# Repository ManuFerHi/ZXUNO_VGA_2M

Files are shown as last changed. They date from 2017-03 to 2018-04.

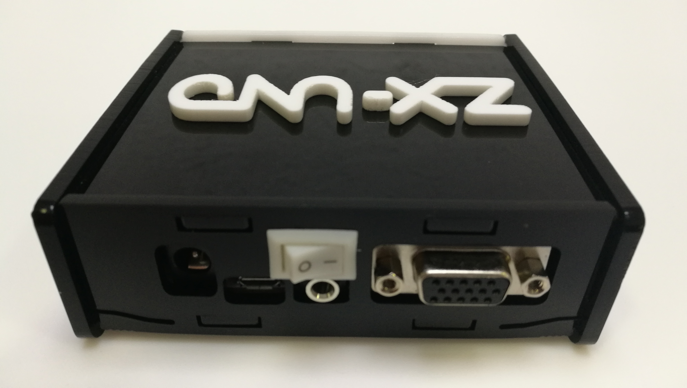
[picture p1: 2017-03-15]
Pics/IMG_20170307_124106.jpg

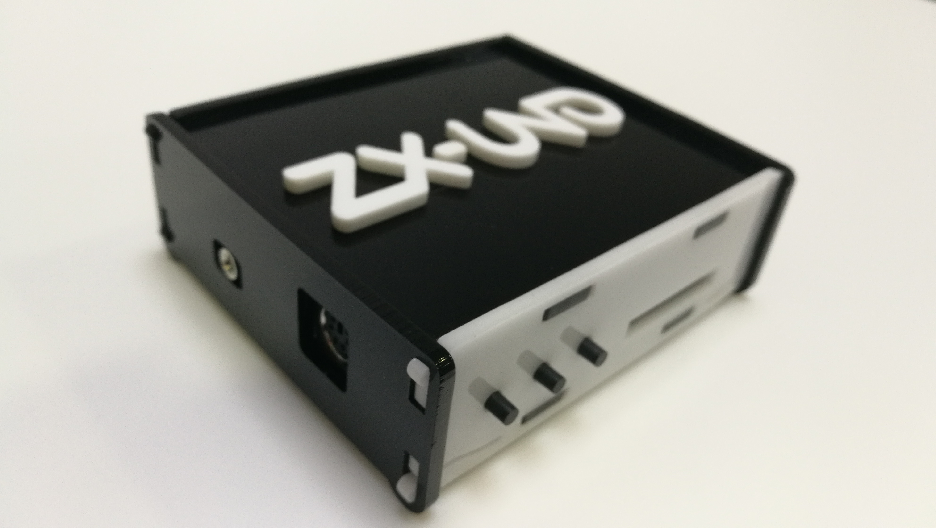
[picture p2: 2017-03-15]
Pics/IMG_20170307_124134.jpg

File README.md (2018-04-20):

# ZXUNO_VGA_2M
FPGA BOARD based on ZX-UNO project, this version include 2Mb SRAM, W25Q128 Flash chip and 2 joystick ports. VGA and RGB native output.




For more information, contact with manuferhi@gmail.com

Based on ZX-UNO project by Superfo, Mcleod, Quest, AVillena and Hark0.
http://zxuno.speccy.org/

(CC BY-SA)License.

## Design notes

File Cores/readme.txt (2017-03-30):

Para instalar un core o reemplazar versión, descargar el fichero CORE(X).ZX1 y renombrar X=SLOT que ocupa en vuestro Zx-Uno, colocar en el directorio raiz y seleccionar en bios menú update el slot dónde alojar el core.

To install a core or replace version, download the file CORE (X) .ZX1 and rename X = SLOT that occupies in your Zx-Uno, place in the root directory and select in bios menu update the slot where to host the core.

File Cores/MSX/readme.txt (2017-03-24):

Autor Fabio.

25/03/2017

Add VGA video output.

I made a MSX1 core, with a SCC Megaram from OCM. Specifications:

- MSX1 USA, 60Hz vertical frequency.
- 128K RAM Mapper.
- 128K Nextor (MSX-DOS2 evolution) ROM with SD driver.
- 256K of RAM to Megaram SCC/SCC+ from OCM project.
- Keyboard PT-BR layout (for a while).
- Simple switched I/O ports (no software yet).
- Multiple boards, incluing ZX-Uno.
- CVBS video only, no scandoubler yet.

The binaries are located here:

https://drive.google.com/drive/folders/0B5wpc_jDN_n0Z1BvSms2YWJHWGc

Format a SD Card in FAT16 (4GB max) and unzip the 'msx1_sd_files.zip' file in SD card root.

The MSX 1 FPGA contains a IPL loader to clear the RAM and load the 'NEXTOR.ROM' SD file to RAM. The ROM is implemented in Xilinx BlockRAM.

CTRL+ALT+DEL is soft reset, CTRL+ALT+F12 is hard reset (run IPL again) and CTRL+ALT+BACKSPACE is ZX-Uno Standard, reload first core from SPI Flash.

The joystick port is mapped to JoyMega, configure the ZX-Uno hardware to SEGA Genesis joypad.

To load ROM in SCC Megaram, uses the ROMLOAD.COM (it is in SD files) with '/S' switch for starting:

ROMLOAD game.rom /S

The core is in beta stage yet, sources will be released soon.

Thanks.

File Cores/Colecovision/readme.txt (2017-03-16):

# colecofpga
Colecovision FGPA port from old PACE project.

The original project information is here:
http://members.iinet.net.au/~msmcdoug/pace/Nanoboard/nanoboard.html

This project is a ColecoFPGA design port to the Terasic DE-1 and DE-2 development boards, ZX-Uno board and a stand-alone version with a EP2C5 Chinese board.

The Hardware folder is the Eagle project for the prototype. In Synth folder there are projects for all cards. The prototype 1 did not work and is abandoned, the project with the EP4C10 card is not completed.

The second prototype use SNES control to emulate all of the original joystick buttons. Holding TL button the original buttons simulate:

<pre>
Y      => 1
X      => 2
B      => 3
A      => 4
SELECT => 5
START  => 6
</pre>

Holding TR button the original buttons simulate:

<pre>
Y      => 7
X      => 8
B      => 9
A      => 0
SELECT => *
START  => #
</pre>

Holding START and SELECT together resets the machine, returning in the multcart menu.

The B button and Y (auto-fire) is the fire 1 of original joystick. The A button and X (auto-fire) is the fire 2.

For the DE-1, DE-2 and ZX-Uno boards the PS/2 keyboard emulates the original joystick:

The arrow keys simulate the original directional. Z key is the 'fire 1', X key is 'fire 2', 0-9 is '0-9', Q key is '*' and W key is '#'. ESC key resets the machine. For the ZX-Uno the joystick port also works for directionals and fire 1.

The key combination CTRL+ALT+BACKSPACE, on ZX-Uno version, reloads the main core of Xilinx, returning to the main menu.

In this circuit the BIOS ROM is loaded from the SD card as well as the ROM multcart. In the source folder 'SD_Card' contains all necessary files to the SD card. Format it to FAT16 and copy the files.

In multcart menu, use the directionals to navigate the ROMs and use FIRE 1 button to load the selected ROM.

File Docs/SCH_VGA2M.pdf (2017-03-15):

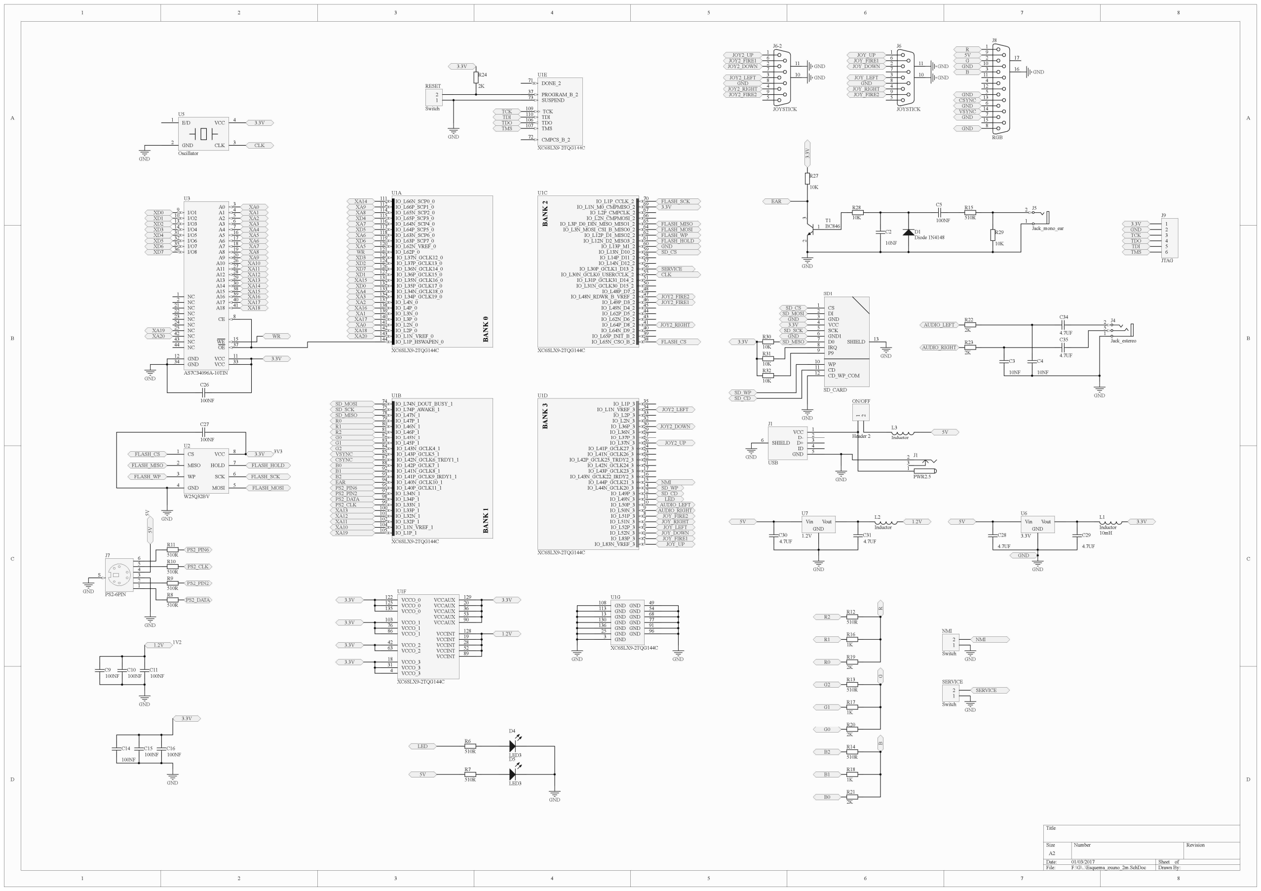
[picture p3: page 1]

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
Title

Size | Number | Revision
A2
Date: | 01/03/2017 | Sheet of
File: | F:\G\..\Esquema_zxuno_2m.SchDoc | Drawn By:
144 | IO_L1P_HSWAPEN_0 | BANK ⁰ IO_L1N_VREF_0 143 | IO_L2P_0 142 | IO_L2N_0 141 | IO_L3P_0 140 | IO_L3N_0 139 | IO_L4P_0 138 | IO_L4N_0 137 | IO_L34P_GCLK19_0 134 | IO_L34N_GCLK18_0 133 | IO_L35P_GCLK17_0 132 | IO_L35N_GCLK16_0 131 | IO_L36P_GCLK15_0 127 | IO_L36N_GCLK14_0 126 | IO_L37P_GCLK13_0 124 | IO_L37N_GCLK12_0 123 | IO_L62P_0 121 | IO_L62N_VREF_0 120 | IO_L63P_SCP7_0 119 | IO_L63N_SCP6_0 118 | IO_L64P_SCP5_0 117 | IO_L64N_SCP4_0 116 | IO_L65P_SCP3_0 115 | IO_L65N_SCP2_0 114 | IO_L66P_SCP1_0 112 | IO_L66N_SCP0_0 111

U1A

XC6SLX9-2TQG144C

105 | IO_L1P_1 | BANK ¹ IO_L1N_VREF_1 104 | IO_L32P_1 102 | IO_L32N_1 101 | IO_L33P_1 100 | IO_L33N_1 99 | IO_L34P_1 98 | IO_L34N_1 97 | IO_L40P_GCLK11_1 95 | IO_L40N_GCLK10_1 94 | IO_L41P_GCLK9_IRDY1_1 93 | IO_L41N_GCLK8_1 92 | IO_L42P_GCLK7_1 88 | IO_L42N_GCLK6_TRDY1_1 87 | IO_L43P_GCLK5_1 85 | IO_L43N_GCLK4_1 84 | IO_L45P_1 83 | IO_L45N_1 82 | IO_L46P_1 81 | IO_L46N_1 80 | IO_L47P_1 79 | IO_L47N_1 78 | IO_L74P_AWAKE_1 75 | IO_L74N_DOUT_BUSY_1 74

U1B

XC6SLX9-2TQG144C | BANK ² | IO_L1P_CCLK_2 | 70
| | IO_L1N_M0_CMPMISO_2 | 69
| | IO_L2P_CMPCLK_2 | 67
| | IO_L2N_CMPMOSI_2 | 66
| | IO_L3P_D0_DIN_MISO_MISO1_2 | 65
| | IO_L3N_MOSI_CSI_B_MISO0_2 | 64
| | IO_L12P_D1_MISO2_2 | 62
| | IO_L12N_D2_MISO3_2 | 61
| | IO_L13P_M1_2 | 60
| | IO_L13N_D10_2 | 59
| | IO_L14P_D11_2 | 58
| | IO_L14N_D12_2 | 57
| | IO_L30P_GCLK1_D13_2 | 56
| | IO_L30N_GCLK0_USERCCLK_2 | 55
| | IO_L31P_GCLK31_D14_2 | 51
| | IO_L31N_GCLK30_D15_2 | 50
| | IO_L48P_D7_2 | 48
| | IO_L48N_RDWR_B_VREF_2 | 47
| | IO_L49P_D3_2 | 46
| | IO_L49N_D4_2 | 45
| | IO_L62P_D5_2 | 44
| | IO_L62N_D6_2 | 43
| | IO_L64P_D8_2 | 41
| | IO_L64N_D9_2 | 40
| | IO_L65P_INIT_B_2 | 39
| | IO_L65N_CSO_B_2 | 38

U1C

XC6SLX9-2TQG144C BANK ³ | IO_L1P_3 | 35
IO_L1N_VREF_3 | 34
IO_L2P_3 | 33
IO_L2N_3 | 32
IO_L36P_3 | 30
IO_L36N_3 | 29
IO_L37P_3 | 27
IO_L37N_3 | 26
IO_L41P_GCLK27_3 | 24
IO_L41N_GCLK26_3 | 23
IO_L42P_GCLK25_TRDY2_3 | 22
IO_L42N_GCLK24_3 | 21
IO_L43P_GCLK23_3 | 17
IO_L43N_GCLK22_IRDY2_3 | 16
IO_L44P_GCLK21_3 | 15
IO_L44N_GCLK20_3 | 14
IO_L49P_3 | 12
IO_L49N_3 | 11
IO_L50P_3 | 10
IO_L50N_3 | 9
IO_L51P_3 | 8
IO_L51N_3 | 7
IO_L52P_3 | 6
IO_L52N_3 | 5
IO_L83P_3 | 2
IO_L83N_VREF_3 | 1

U1D

XC6SLX9-2TQG144C

PROGRAM_B_2 37

CMPCS_B_2 72

DONE_2 71

TCK 109
TDI 110
TMS 107 TDO 106

SUSPEND 73

U1E

XC6SLX9-2TQG144C

VCCAUX | 129
VCCAUX | 20
VCCAUX | 36
VCCAUX | 53
VCCAUX | 90
VCCINT | 128
VCCINT | 19
VCCINT | 28
VCCINT | 52
VCCINT | 89

VCCO_0 122
VCCO_0 125
VCCO_0 135

VCCO_1 103
VCCO_1 76
VCCO_1 86

VCCO_2 42
VCCO_2 63

VCCO_3 18
VCCO_3 31
VCCO_3 4

U1F

XC6SLX9-2TQG144C

GND 108
GND 113
GND 13
GND 130
GND 136
GND 25
GND 3
GND | 49
GND | 54
GND | 68
GND | 77
GND | 91
GND | 96

U1G

XC6SLX9-2TQG144C

A15 | 38 A14 | 30 A13 | 29 A12 | 28 A11 | 27 A10 | 26 A9 | 20 A8 | 19
WE | 15
A17 | 40
A7 | 18 A6 | 17 A5 | 16 A4 | 7
A3 | 6
A2 | 5
A1 | 4
A0 | 3
VCC | 33 GND 12
OE | 37

NC 21

I/O1 9

NC 22

I/O2 10

NC 23

I/O3 13

NC 24

I/O4 14

NC 25

I/O5 31

NC 42

I/O6 32

NC 43

I/O7 35

NC 44

GND 34

A16 | 39
VCC | 11
A18 | 41 NC 2

NC 1

CE 8

I/O8 36

U3

AS7C34096A-10TIN

E/D 1

GND 2

VCC | 4
CLK | 3

U5

Oscillator

Vin Vout
GND

U6

3.3V

Vin Vout
GND

U7

1.2V

2

1

5

J4

Jack_estereo

2

1

J5

Jack_mono_ear

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
JOYSTICK

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
PS2-6PIN

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
JTAG 1

2

ON/OFF

Header 2

1

2

RESET

Switch

D1
Diode 1N4148

D4

LED3
D5

LED3

3
1 2

T1
BC846

10mH

L1

Inductor

L2

Inductor

L3

Inductor

510R

R6

510R

R7

510R

R8

510R

R9

510R

R10

510R

R11

510R

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
10NF

C2

10NF

C3

10NF

C4

100NF

C11

100NF

C14

100NF

C26

100NF

C27

100NF

C5

100NF

C9
100NF

C10

4.7UF

C28

4.7UF

C29
4.7UF

C30
4.7UF

C31

4.7UF

C34

4.7UF

C35

FLASH_SCK

FLASH_SCK

3.3V

FLASH_MISO
FLASH_MOSI
FLASH_WP
FLASH_HOLD
GND
SD_CS

CLK

FLASH_CS

SD_MOSI
SD_SCK
SD_MISO
R0
R1
R2
G0
G1
G2
VSYNC
CSYNC
B0
B1
B2
EAR
PS2_PIN6
PS2_PIN2
PS2_DATA
PS2_CLK
XA13
XA12
XA11
XA10
XA19

XA14
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
XA15
XD0
XA4
XA3
XA2
XA16
XA1
XA17
XA0
XA18
WR | XA20

3.3V

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
XA10
XA11
XA12
XA13
XA14
XA15
XA16
XA17
XA18

XA19
XA20

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
3.3V

GND

3.3V

GND

CLK

3.3V

3.3V

GND

3.3V

3.3V

FLASH_CS

FLASH_MISO

FLASH_WP

FLASH_HOLD

FLASH_MOSI

3.3V

GND

PS2_PIN6

PS2_CLK

PS2_PIN2

PS2_DATA ⁵V

GND

1.2V

GND

100NF

C15
100NF

C16

3.3V

GND

3.3V

LED
AUDIO_LEFT
AUDIO_RIGHT
JOY_FIRE2
JOY_RIGHT
JOY_LEFT
JOY_DOWN
JOY_FIRE1
JOY_UP

1.2V

GND | GND

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
5V | 1.2V

GND

5V | 3.3V

3.3V
GND
TCK
TDO
TDI
TMS

JOY_UP

JOY_DOWN

JOY_LEFT

JOY_RIGHT

JOY_FIRE1

GND

JOY_FIRE2

SD_CS
SD_MOSI
GND
3.3V
SD_SCK
GND
3.3V | SD_MISO

GND

GND

5V

AUDIO_LEFT

AUDIO_RIGHT

GND ³.3V

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
VSYNC

CSYNC

5V

CS 1

MISO 2

WP 3

GND 4

VCC | 8
HOLD | 7
SCK | 6
MOSI | 5

U2

W25Q32BV

VCC | 1
D- | 2
D+ | 3
ID | 4
GND | 5

SHIELD 6

J1

USB

CS 1
DI 2
GND 3
VCC 4
SCK 5
GND1 6
D0 7
IRQ 8
P9 9

WP 10
CD 11
CD_WP_COM 12

SHIELD 13

SD1

SD_CARD

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
J6-2

JOYSTICK

1

2
3

J1

PWR2.5

510R

R12

510R

R13

510R

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
R G B

3V3 5V

1V2

GND

JOY2_UP
JOY2_FIRE1
JOY2_DOWN

JOY2_LEFT
GND
JOY2_RIGHT
JOY2_FIRE2

JOY2_UP

JOY2_FIRE1

JOY2_DOWN

JOY2_LEFT

JOY2_RIGHT

JOY2_FIRE2

1

2

NMI

Switch

1

2

SERVICE

Switch

NMI

NMI

GND

GND

SERVICE

SERVICE

SD_WP
SD_CD

SD_WP
SD_CD

GND

GND

GND

GND

GND

GND

GND

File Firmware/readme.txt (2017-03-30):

Rename file to firmware.zx1 and put in SD root. Select in bios menu update option "Update bios" then select SD option.

Renombrar el fichero a firmware.zx1 y colocarlo en el directorio raiz de la SD, seleccionar en la bios menú update opción update bios y opción SD.

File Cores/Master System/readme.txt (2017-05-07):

This is a port of the Ben Leperchey's Sega Master System HDL core to the ZX-UNO board.
Original source code: https://github.com/ben0109/Papilio-Master-System

All credits go to Ben. 
Ben's Blog: http://fpga-hacks.blogspot.com.es/

Ported to ZX-UNO by Quest of ZX-UNO team (http://www.zxuno.com)
2 joy supported.

As per original author's request, and following the ZX-UNO open source rules, every source code change, addition, improvement, etc, is available freely at ZX-UNO SVN repository

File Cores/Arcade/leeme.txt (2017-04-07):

Características comunes a todos los cores:
------------------------------------------

- 2 modos de vídeo seleccionables: RGB (PAL60Hz) y VGA 60Hz (conmutable con tecla Bloq. Despl / Scroll Lock)

- Soporte de scanlines en VGA (conmutable con la tecla "-" del teclado numérico)

- Autodetección del modo de vídeo de la BIOS del ZX-UNO.

- Reset de la máquina (pulsando F12)

- Añadido Master Reset para volver al core de Spectrum (con Ctrl+Alt+Backspace)

- Controles de jugador tanto en teclado como en joystick:

 ** Las direcciones en el teclado son, tanto los cursores como QAOP. Disparos 1 y 2 en teclas Z y X. También comparten dichas teclas en algunos casos la inserción de moneda y el boton Start. Lo mismo para el joystick. Es necesario un joystick o pad de 2 botones. Dependiendo de cada juego el mapeo de estas funciones puede estar intercambiado (para evitar meter monedas cuando disparas, etc, ya que cada juego lo hace diferente).

- Implementada conmutación opcional para el giro de 90º en las direcciones de los controles (pulsando la tecla TAB). Por defecto arrancan con los controles normales, para el uso de pantallas verticales. Si tienes la pantalla en horizontal (lo más habitual), la imagen se ve girada, pero para ayudar en el control, y que sea más natural y acorde con lo que se ve, pulsando TAB se consigue que las direcciones arriba-abajo estén intercambiadas con izquierda-derecha. Afecta por igual al joystick y al teclado.

COMO GRABAR LOS CORES EN EL ZX-UNO:
-----------------------------------
Para grabar los cores en el ZX-UNO, renombrar cada archivo .ZX1 a COREx.ZX1, siendo "x" el numero de slot que queremos que ocupe en la memoria flash del ZX-UNO. Copiar a la tarjeta SD, encender el ZX-UNO, pulsar F2 al arranque para entrar en BIOS, ir a la pestaña Upgrade y seleccionar el slot correspondiente, elegir grabar desde SD y al finalizar escribir el nombre del core.

Para lanzar el core una vez grabado, al arranque del Zx-UNO, pulsar Bloq. Mays (Caps Lock) y elegirlo de la lista que sale.

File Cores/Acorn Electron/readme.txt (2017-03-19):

TEST1 (8-Ene-2016)

Es un port del trabajo original de David Banks (hoglet), como todo lo que tenemos de Acorn hasta el momento (fuentes originales en https://github.com/hoglet67/ElectronFpga).

Ya está subido el fuente para el ZX-UNO y el .bit tanto para v2 como v3 (vale para ambos puesto que no usa la SRAM) en el repositorio SVN habitual.

Funciones actuales:

- Salida vídeo compuesto/RGB y VGA 50Hz seleccionables vía teclado. Por defecto arranca en RGB/Vcomp. Tecla RePag = VGA, tecla AvPag = RGB/Vcomp. También hay otros modos (60Hz, etc) usando combinaciones de ctrl+CapsLock+1 al 4)
- Soporte SD/MMC, vía archivos de imagen ".MMB" (BEEB.MMB, que son contenedores de imágenes de disquete). Explicado más abajo para que funcione correctamente (al igual que pasa con el core de BBC Micro)
- Carga de software via cinta/audo por el puerto EAR del ZX-UNO.
- Teclado PS/2 (mapeado a teclado inglés)
- Sonido estándar.
- Reset (tecla F10 y ctrl+F10)

El core usa una rom (Smart SPI) que lee de la SD un archivo normalmente grande, que contiene imágenes de disquete, que debe tener el nombre de BEEB.MMB en el directorio raíz. Este archivo lo podéis crear vosotros mismos con una utilidad incluida (MMBImager.exe) o bien descargar uno preparado con software y juegos, de los que hay por la red para Acorn Electron (por ejemplo, este, ajeno a este foro: https://mega.nz/#!ZE8FxQSC!EN89saPfSfO0 ... SAOvhdbGJA)

Pero no basta con copiarlo directamente a la SD si ya hay cosas dentro, y seguramente al 99% que no lea correctamente dando corrupciones. Por tanto para que funcione 100% bien:

1- Formatear una SD (si no es muy grande, mejor) en FAT o FAT32, pero NO en formato rápido (en Windows, desmarcar la casilla de formato rápido). Esto es muy importante.
2- Copiar a la SD el archivo BEEB.MMB, de modo que este sea el PRIMER archivo que se copia a la SD.
3- Si se desea, ya se pueden copiar otros archivos a la SD para usar con otros cores, pero SIEMPRE debe mantenerse el BEEB.MMB como el primero que se copió a la SD. Es muy importante.

Una vez metida la SD en el ZX-UNO y arrancado el core, si el archivo de antes (BEEB.MMB) está bien grabado y reconoce bien la SD. Al arrancar debería aparecer:

CÓDIGO: SELECCIONAR TODO
Acorn Electron
Smart SPI
BASIC
>

Automáticamente se automonta el disco 0 de la imagen, podemos ver su contenido tecleando *CAT
Por algún motivo que desconozco, a diferencia de lo que pasa en el core de BBC micro que autoarranca si el disco tiene Boot al pulsar shift+F10 y tampoco van los comandos de carga de binarios (como *RUN) pero sí podemos cargar cargadores BASIC sin problemas:

Para cargar el menú de juegos que viene en la imagen precargada que comentaba antes, tecleamos: CHAIN"MENU"

Para cargar desde cassete/Entrada de audio EAR, he incluido en la carpeta "varios" el programa FreeUEF.exe que sirve para reproducir cintas en formato UEF en el PC. Viene una de ejemplo de una revista. También las convierte a WAV para reproducirlos luego desde otro dispositivo como el móvil.

Para cargar de cinta: Tecleamos primero: *TAPE
Y después: CHAIN"" y pulsamos PLAY.

Y eso es todo. Para resetear, en este caso es F10 o ctrl+F10.

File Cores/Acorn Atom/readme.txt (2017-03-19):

TEST1 (17-Ago-2015)

El código original del usuario Hoglet, en el que se ha basado el port, está disponible aquí: https://github.com/hoglet67/AtomFpga.

Post escrito por Quest originalmente en Zona de Pruebas.
Enlace original:
http://www.zonadepruebas.com/viewtopic. ... 754#p59754

Otro sistema más funcional en el ZX-UNO (Y van 5) :D

En esta ocasión he portado el core del Acorn Atom
Más abajo pongo el link de descarga del bitfile / mcs para el que lo quiera probar :)

Tiene soporte para cargar el software con tarjeta SD.

Como en la ocasión anterior con el de SMS, ha habido que remapear todos los pines, crear nuevos relojes a aprtir de nuestro oscilador de 50Mhz, eliminar señales que daban problemas (como las de los joystick), cambiar ligeramente el código del teclado para que funcionara en el ZX-UNO, etc. El código original, en el que se ha basado el port está disponible aquí: https://github.com/hoglet67/AtomFpga , del usuario Hoglet.

Para hacerlo funcionar en el ZX-UNO:

- Meter el bitfile a la FPGA (o el mcs para la flash)
- Enchufar un teclado PS/2 al l ZX-UNO
- Enchufar la plaquita VGA al conector J8 y conectarlo a un monitor VGA normal. (no va por vídeo compuesto, sólo VGA de momento)
- Enchufar el jack de salida de audio a unos altavoces.
- Preparar una tarjeta SD formateada en FAT. Bajad de aquí: http://www.stardot.org.uk/forums/viewto ... =44&t=6544 el archivo "AtomSoftwareArchive_20150504_V8.zip" y descomprimidlo tal cual en la raíz de la SD (si no va la SD, probad con otra distinta). Y meterla en el ZX-UNO.

Y ahora, a funcionar:

- Al enchufar el ZX-UNO ya arranca en modo BASIC del Atom. El bitfile del core ya viene con la extensión AtoMMC2 incorporada, con lo cual, disponemos de carga mediante la SD:
- Para lanzar el menú de selección de software que hemos cargado en la SD previamente, pulsamos SHIFT+F10 (si no va a la primera intentarlo más veces, a veces no va 100% fino)
- A disfrutar.

- Para volver a sacar el menú: SHIFT+10
- Resetear el Atom: F10
- Modos turbo: F1 = 1Mhz, F2 = 2Mhz, F3 = 4Mhz, F4 = 8Mhz
- El mapeado del teclado es inglés. Tenedlo en cuenta, porque no coinciden algunas teclas con el español. Mirad una foto de uno inglés para comparar.

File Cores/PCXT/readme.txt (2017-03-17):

Autor Distwave.

- Eliminado el PSG para el sonido Tandy 3-voice. Se ha reducido notablemente el ruido de fondo.
- Solucionados los gitches en modo texto.
- BIOS Incorporada en el core, ya no es necesario grabarla en los últimos 8 KB de la SD. Ahora se aloja en la BRAM utilizada como memoria de vídeo y el bootloader la copia a la memoria RAM en el primer arranque (tal y como sugirió antoniovillena).
- Frecuencia de trabajo de la memoria SRAM aumentada de 50 MHz a 75 MHz. Este cambio aumenta el rendimiento del core notablemente, aunque el procesador siga funcionando a 25 MHz.
- Mapeo directo de los 2 MB de SRAM en los primeros 2 MB direccionables. La distribución de la memoria queda de la siguiente forma:
· 640 KB de memoria convencional
· 224 KB de memoria superior
· 32 KB para alojar la BIOS
· 64 KB de memoria alta
· 448 KB de memoria extendida (XMS)

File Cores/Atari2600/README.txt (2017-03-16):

Port of the A2601 FPGA implementation for the ZXUNO
---------------------------------------------------------------------------------

Limitations:
- Needs a PS/2 keyboard to access the menu (Esc key) and load roms
- supports only player one controller

All zxuno related files including the Quartus project files are in the 'zxuno' subdirectory.

2016 DistWave

Original readmes:

Port of the A2601 FPGA implementation for the MiST
---------------------------------------------------------------------------------

Buttons:
- right MiST button -> Start
- Keyboard 1        -> Select
- Keyboard 2        -> BW/Color (yellow led on = Color)
- Keyboard F12      -> OSD to select roms from the sd card (needs extension .a26)

Current limitations:
- supports only the common Atari bank switching schemes
- no illegal opcodes

All MiST related files including the Quartus project files are in the 'mist' subdirectory.

Homepage: http://ws0.org/tag/ma2601/

Original readme below :)

Port of the A2601 FPGA implementation for the Turbo Chameleon
---------------------------------------------------------------------------------

The ROM cartridge is the GPL licensed game Hunchy, see
http://www.atariage.com/forums/topic/67953-hunchy-my-first-2600-homebrew-game/
converted to hex file format with 
http://www.ht-lab.com/freeutils/bin2hex/bin2hex.html

Copyright 2012 Frank Buss

Original readme:

A2601: An FPGA-based clone of the Atari 2600 video game console (Release 0.1.0)
---------------------------------------------------------------------------------

This archive contains source code for VHDL implementation and Python script 
utilities for the A2601 video game console project.

VHDL source code provided includes implementation of the 6502(7) CPU, the TIA, 
the 6532 RIOT, additional audio/video/joypad circuitry and bankswitching schemes 
plus additional RAM used by some game cartridges. Test benches are supplied for 
all main components (although they may be slightly out of date).

The 6502 CPU core has been developed from scratch for this project. It contains 
hand-crafted finite state machine and controls that implement all documented 
6502 opcodes. It synthesizes quickly and has good performance in the simulator. 

The TIA implementation digitally synthesizes NTSC composite video signal via a 
lookup table that contains a sequence of values that signifies a sine wave at 
correct phase for each one of the 16 chrominance values selectable in the TIA. 

You should be able to synthesize the A2601 in Xilinx ISE without any major 
problems. No project files are included, but it is best to create these 
yourself, anyway. Two top level entities are provided: One reads cartridge ROM 
data from on-board flash memory, the other stores the ROM data in the FPGA 
built-in SRAM. It is also possible to run A2601 sources in a VHDL simulator. 
Some helper utilities and a test bench are provided for this purpose in the 
A2601/util directory.

For more information, visit the project website at 
<http://retromaster.wordpress.com/a2601>.

All source code and other content found in this archive is subject to GNU 
General Public License Version 3. See the included LICENSE.TXT file for details.

Copyright 2006, 2007, 2010 Retromaster.

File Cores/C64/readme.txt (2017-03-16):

Autor Quest.

BETA7b (01-Mar-2017)

Se modifica los "timings" y también los accesos a memoria para que no estén tan apurados, por lo que ahora se escucha correctamente el sonido en ciertos ZX-Uno que antes no lo hacían.
Se realizan ciertos cambios internos que mejoran la compatibilidad, cargando ahora juegos como el Robocop 3.
Para añadir estas mejoras ha sido necesario quitar la detección de los "settings" de vídeo al inicio durante el "reset".

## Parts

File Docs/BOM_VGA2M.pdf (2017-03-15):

Referencia | Descripción | Unidades | Designación
| PCB ZX-Uno VGA 2M | 1
| FPGA XC6SLX9-2TQG144C | 1 | U1
| SPI Flash Winbond W25Q128 | 1 | U2
| IS61WV20488BLL-10TLI | 1 | U3
DM1AA-SF-PEJ | SD socket | 1 | J2
| 6 pin molex connector 1.25mm | 1 | J9
MC001009 | Micro USB socket | 1 | J1
| Oscilator 50MHz 5*7 | 1 | U5
LD1117S33TR | Estabilizador de tensión 3,3V | 1 | U6
LD1117S12TR | Estabilizador de tensión 1,2V | 1 | U7
| 3.5mm audio socket | 2 | J4, J5
| DB9 right angle male | 2 | J6
| DB15 high density RGB | 1 | J8
| PS/2 socket | 1 | J7
| Tira pin 2v+jumper | 1 | SW
| Tact switch 90º | 3 | RESET, S1, S2
1N4148WS-DIO | SMD Diode 1N4148, SOD-323 | 1 | D1
| SMD 0805 LED GREEN | 1 | D5
| SMD 0805 LED RED | 1 | D4
| BC846 SOT-23 NPN Transistor | 1 | T1
| 220 Ohm 0805 Resistor | 2 | R6, R7
| 510 Ohm 0805 Resistor | 8 | R8, R9, R10, R11, R12, R13, R14, R15
| 1K Ohm 0805 Resistor | 3 | R16, R17, R18
| 2K Ohm 0805 Resistor | 6 | R19, R20, R21, R22, R23, R24
| 10K Ohm 0805 Resistor | 6 | R27, R28, R29, R30, R31, R32
| 10nF 0805 Capacitor | 3 | C2, C3, C4
| 100nF 0805 Capacitor | 9 | C5,C11, C16, C26, C27 + (4x cara soldaduras)
| 4.7uF 0805 Capacitor | 6 | C28, C29, C30, C31, C34, C35
| Inductor 1k 0805 | 3 | L1, L2, L3

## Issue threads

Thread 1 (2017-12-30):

Missing PS/2 pull-ups

andykarpov, 2017-12-30:
It's seems there were missing pull-up resistors on PS/2 connector.
Most PS/2 keyboards works fine without them, but USB keyboards connected via USB-to-PS/2 connector fails to detect their mode in this case.

Hotfix is attached, 2x 2k7 resistors was added:
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

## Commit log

2017-03-15 Create Gerbers
2017-04-11 Added Spectrum-KYP core 2 joy
    [Core_Status.xlsx]
2017-06-22 TBBLUE fixed for 2M board
